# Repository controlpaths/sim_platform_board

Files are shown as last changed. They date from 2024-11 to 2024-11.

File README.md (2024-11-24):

# Platform Board

This board is intended to run real time simulation models and connect them to different commercial platforms like Arduino or TI Launchpad. The core of the board is an FPGA able to run models with time steps up to 100ns.

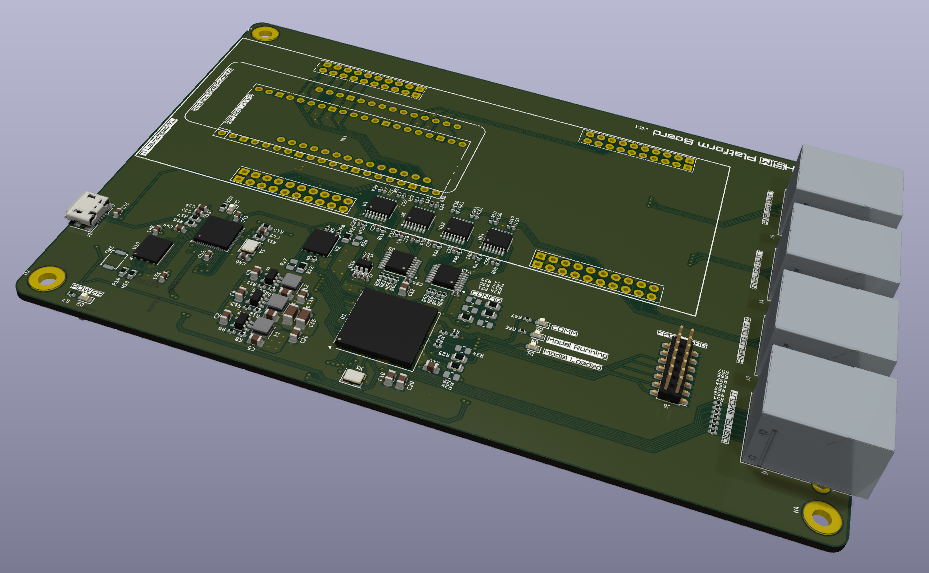
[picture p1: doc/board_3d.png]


The board is based on a 4-layer PCB with an RP2040 as a platform manager. 

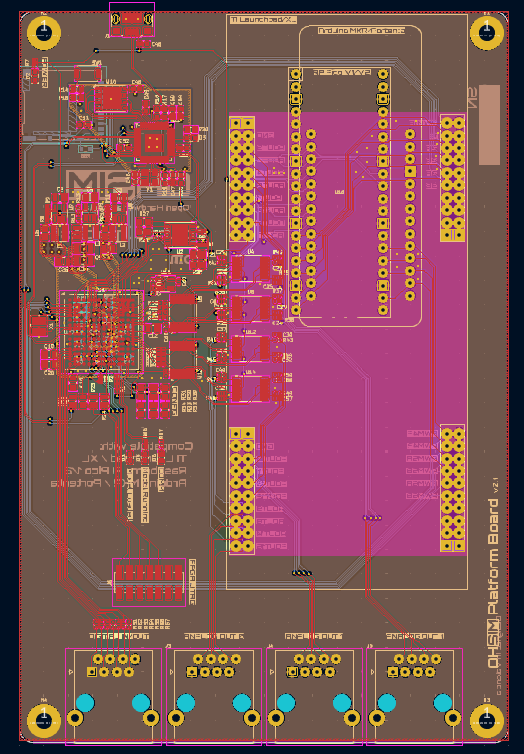
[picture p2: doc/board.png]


## FPGA 

The FPGA used is the AMD Spartan 7 s15 with 15K logic cells. The package used is FTGB196, which makes the board compatible with FPGAs up to 50k logic cells.

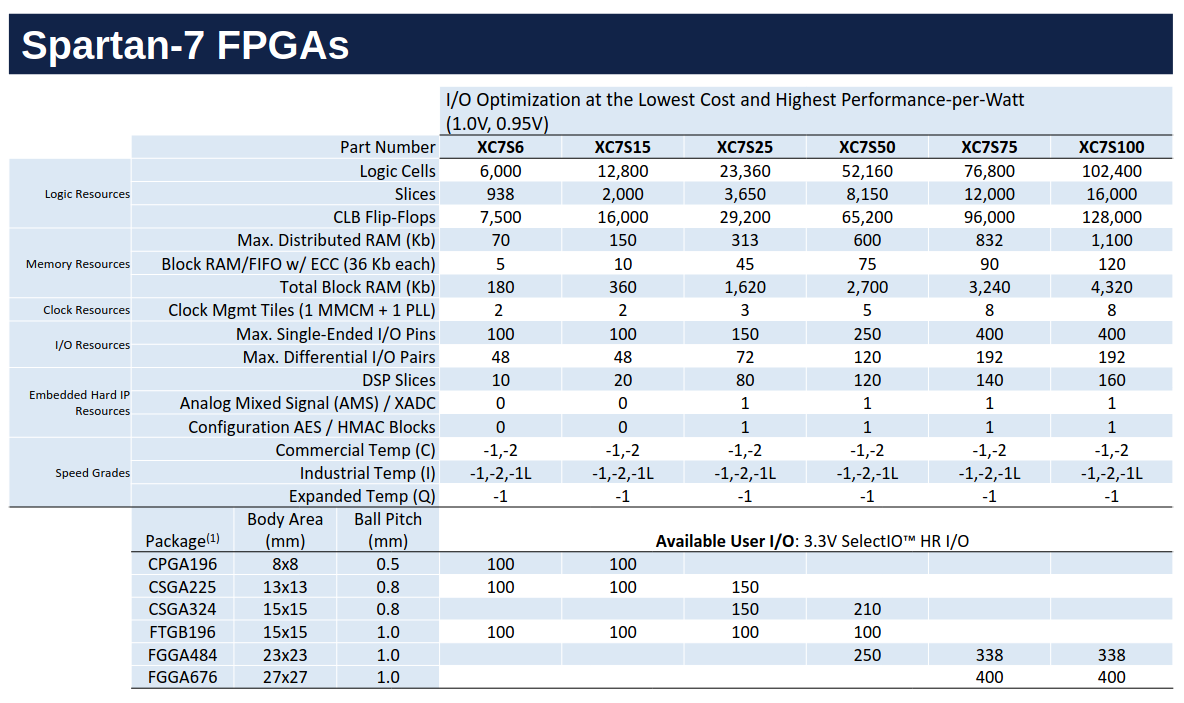
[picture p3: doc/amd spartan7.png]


## DAC outputs

The board features two Digital to Analog converters with 8 channels each. The output range of the DAC is 0 - 3 volts with 12 bit resolutions, and an update rate up to 100 ksps.

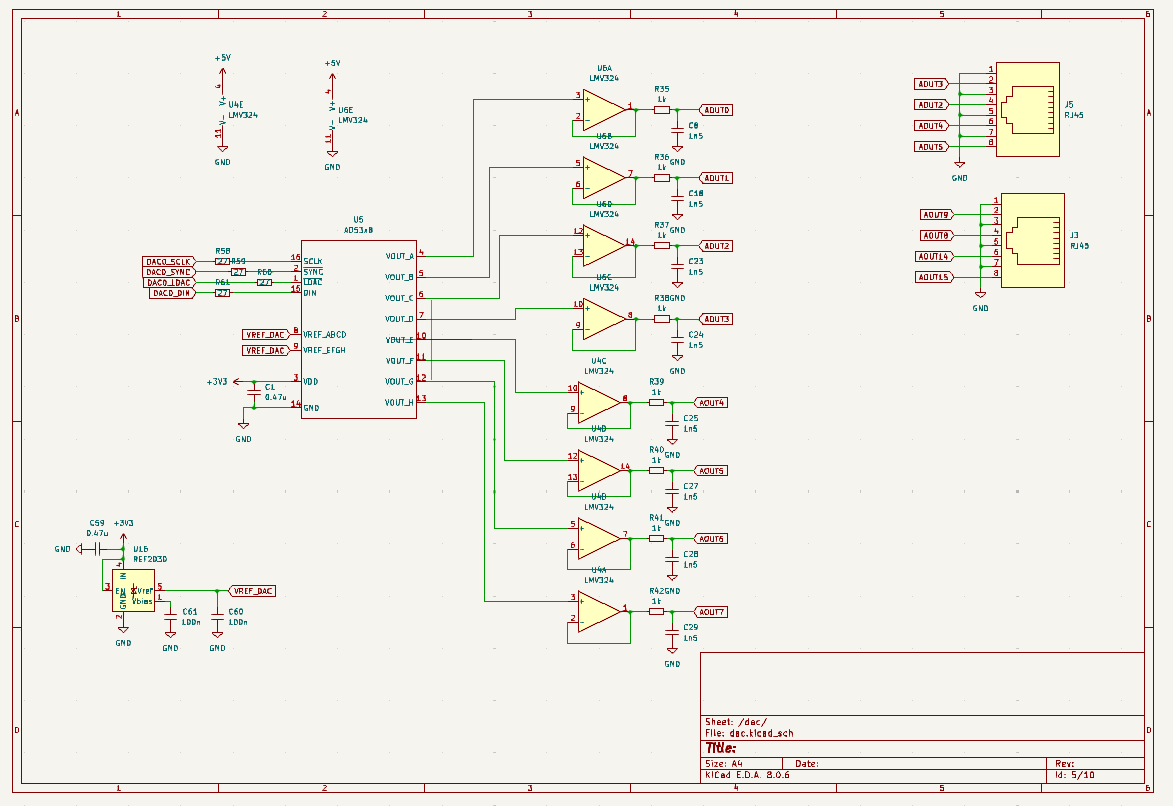
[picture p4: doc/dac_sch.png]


## Control boards

The platform board is compatible with:

- Arduino MKR
- Arduino Portenta
- Raspberry PI Pico
- Texas Instruments Launchpad Boards

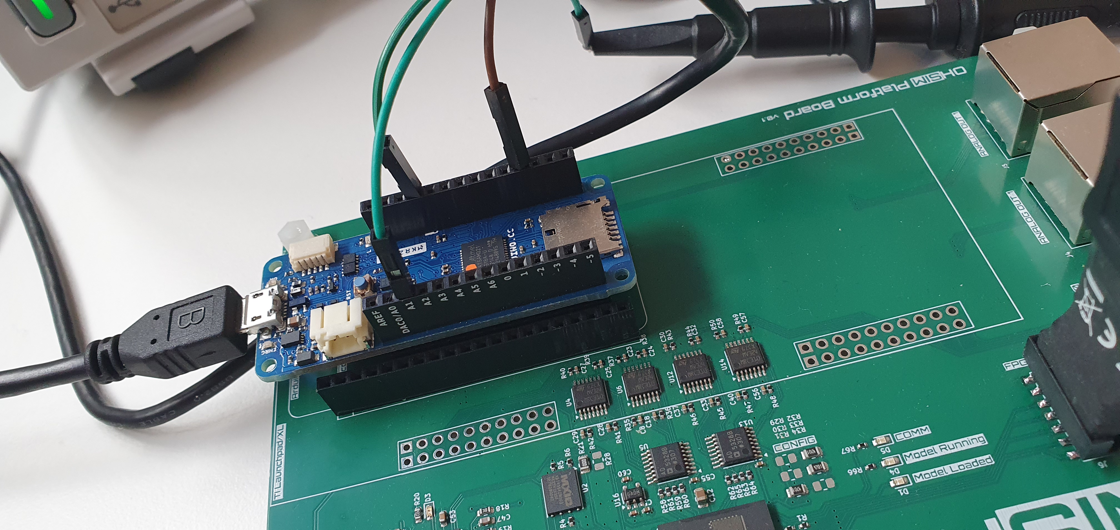
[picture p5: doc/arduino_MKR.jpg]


## Build your own

The Platform Board is open-source, so you can use the output files to manufacture your own in [JLCPCB](https://jlcpcb.com/?from=controlpath). You just need to compress the `production_files` directory, and upload it to [JLCPCB](https://jlcpcb.com/?from=controlpath). 

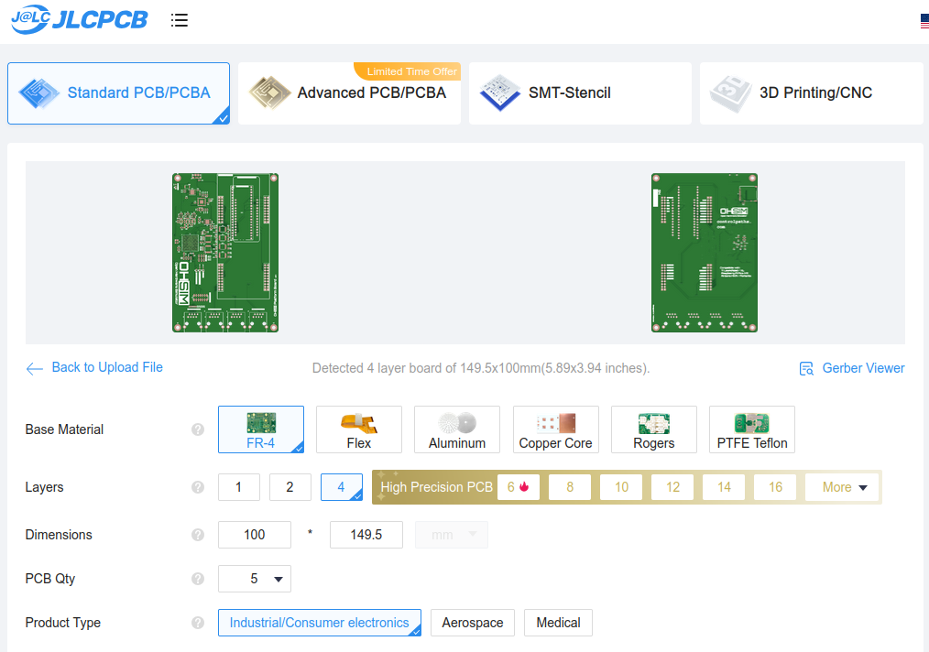
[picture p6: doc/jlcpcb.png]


Remember to change the Surface Finish to **LeadFree HASL** to make your board ROHS compliant.

In a few days, you will receive your board at home.

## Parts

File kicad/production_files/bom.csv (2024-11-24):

Reference | Value | Footprint | Qty | DNP | JLCPCB Part #
C1,C11,C13,C17,C21,C31,C34,C35,C36,C38,C39,C41,C42,C43,C44,C55,C59 | 0.47u | Capacitor_SMD:C_0402_1005Metric | 17 |  | C106255
C2,C3,C4,C10,C12,C14,C16,C19,C20,C22,C26 | 4u7 | Capacitor_SMD:C_0805_2012Metric | 11 |  | C162420
C5,C6,C7 | 10u | Capacitor_SMD:C_0805_2012Metric | 3 |  | C105505
C8,C18,C23,C24,C25,C27,C28,C29,C30,C32,C33,C37,C40,C56,C57,C58 | 1n5 | Capacitor_SMD:C_0402_1005Metric | 16 |  | C106255
C9,C15 | 100u | Capacitor_SMD:C_1206_3216Metric | 2 |  | C268006
C45,C49,C51 | 1u | Capacitor_SMD:C_0603_1608Metric | 3
C46,C47 | 15p | Capacitor_SMD:C_0603_1608Metric | 2
C48,C50,C52,C53,C54 | 100n | Capacitor_SMD:C_0603_1608Metric | 5
C60,C61 | 100n | Capacitor_SMD:C_0402_1005Metric | 2 |  | C106255
D1,D4,D5 | DONE | LED_SMD:LED_0603_1608Metric | 3 |  | C89814
D2 | VCC | LED_SMD:LED_0603_1608Metric | 1 |  | C601673
D3 | LED | LED_SMD:LED_0603_1608Metric | 1 |  | C601673
J1 | USB_B_Micro | Connector_USB:USB_Micro-B_Amphenol_10118193-0001LF_Horizontal | 1 |  | C132562
J2,J3,J4,J5 | RJ45 | Connector_RJ:RJ45_Ninigi_GE | 4 |  | C386758
J7 | Micro_SD_Card_Det_Hirose_DM3AT | Connector_Card:microSD_HC_Hirose_DM3AT-SF-PEJM5 | 1 |  | C114218
L1,L2,L3 | 2u2 | lib:IND_LQH3NPN2R2MMEL | 3 |  | C341775
R1 | 330 | Resistor_SMD:R_0402_1005Metric | 1 |  | C881192
R2,R51,R52,R53,R54,R55,R56,R57 | 100 | Resistor_SMD:R_0402_1005Metric | 8
R3,R4,R5,R6,R66,R67 | 4k7 | Resistor_SMD:R_0402_1005Metric | 6 |  | C3017492
R7 | 10k | Resistor_SMD:R_0402_1005Metric | 1 |  | C328298
R8 | 100k | Resistor_SMD:R_0402_1005Metric | 1 |  | C131362
R9,R12 | 22k | Resistor_SMD:R_0402_1005Metric | 2 |  | C409681
R10 | 240k | Resistor_SMD:R_0402_1005Metric | 1 |  | C323663
R11 | 120k | Resistor_SMD:R_0402_1005Metric | 1 |  | C323683
R13 | 33k | Resistor_SMD:R_0402_1005Metric | 1 |  | C416388
R14,R19 | 1k | Resistor_SMD:R_0603_1608Metric | 2
R15,R18 | 10k | Resistor_SMD:R_0603_1608Metric | 2
R16,R17 | 27 | Resistor_SMD:R_0603_1608Metric | 2
R20,R68 | 4k7 | Resistor_SMD:R_0603_1608Metric | 2
R21,R22 | 0 | Resistor_SMD:R_0805_2012Metric | 2 |  | C3017492
R23,R26,R31,R32,R33 | 4k7 | Resistor_SMD:R_0805_2012Metric | 5
R35,R36,R37,R38,R39,R40,R41,R42,R43,R44,R45,R46,R47,R48,R49,R50 | 1k | Resistor_SMD:R_0402_1005Metric | 16 |  | C409681
R58,R59,R60,R61,R62,R63,R64,R65 | 27 | Resistor_SMD:R_0402_1005Metric | 8
SW1 | SW_Push | Button_Switch_SMD:SW_Push_SPST_NO_Alps_SKRK | 1 |  | C115357
U1 | xc7s25ftgb196 | Package_BGA:Xilinx_FTGB196 | 1 |  | C1521659
U2 | MX25L12833F | Package_SON:WSON-8-1EP_6x5mm_P1.27mm_EP3.4x4mm | 1 |  | C2802978
U4,U6,U12,U14 | LMV324 | Package_SO:TSSOP-14_4.4x5mm_P0.65mm | 4
U5,U13 | AD53x8 | Package_SO:TSSOP-16_4.4x5mm_P0.65mm | 2 |  | C578186
U7,U8,U9 | TLV62565DBVR | Package_TO_SOT_SMD:SOT-23-5 | 3
U10 | W25Q32JVZP | Package_SON:WSON-8-1EP_6x5mm_P1.27mm_EP3.4x4.3mm | 1 |  | C2940197
U11 | RP2040 | Package_DFN_QFN:QFN-56-1EP_7x7mm_P0.4mm_EP3.2x3.2mm | 1
U16 | REF2030 | Package_TO_SOT_SMD:SOT-23-5 | 1 |  | C528704
X1 | SG-8018CE | Crystal:Crystal_SMD_3225-4Pin_3.2x2.5mm | 1 |  | C390488
Y1 | 12MHz | Crystal:Crystal_SMD_3225-4Pin_3.2x2.5mm | 1 |  | C524716

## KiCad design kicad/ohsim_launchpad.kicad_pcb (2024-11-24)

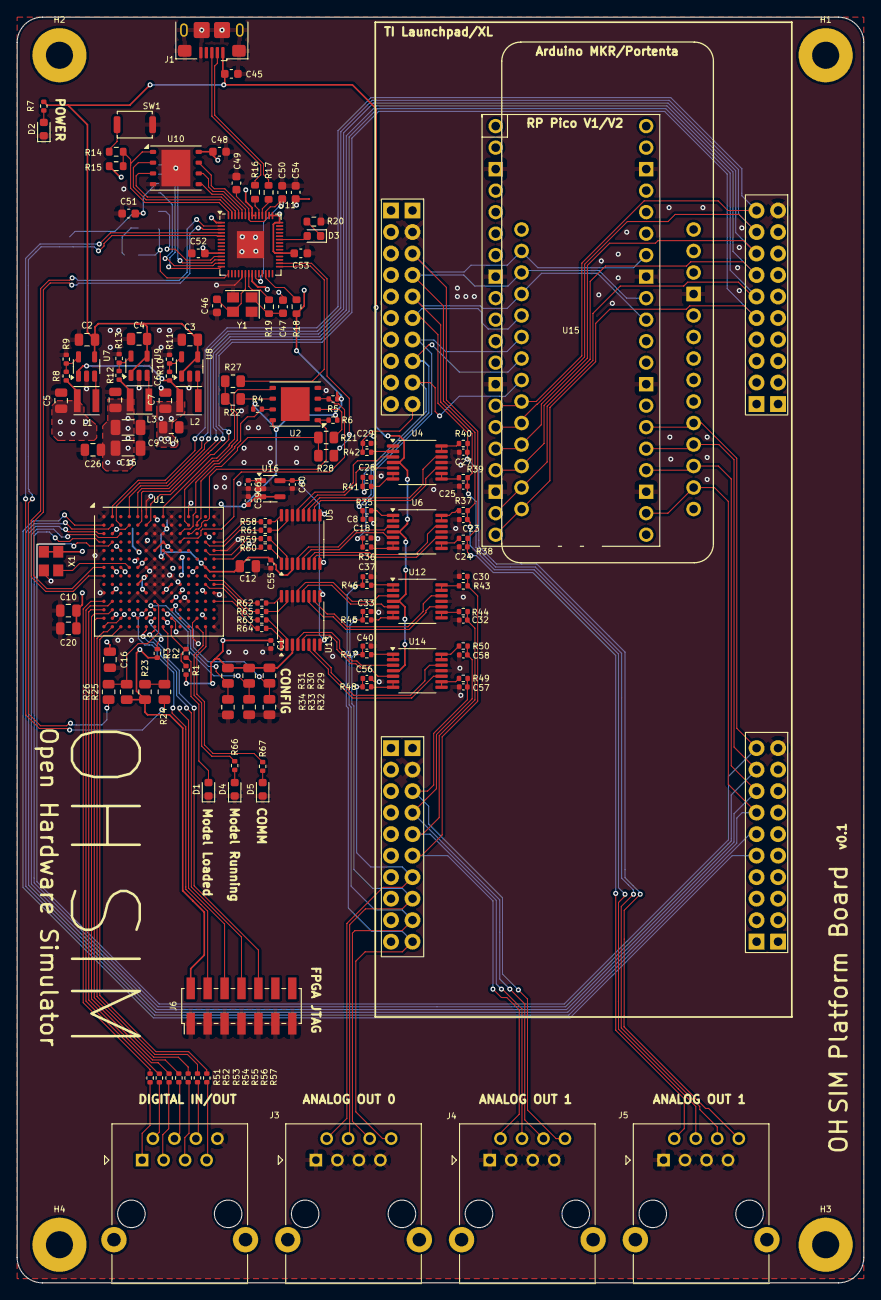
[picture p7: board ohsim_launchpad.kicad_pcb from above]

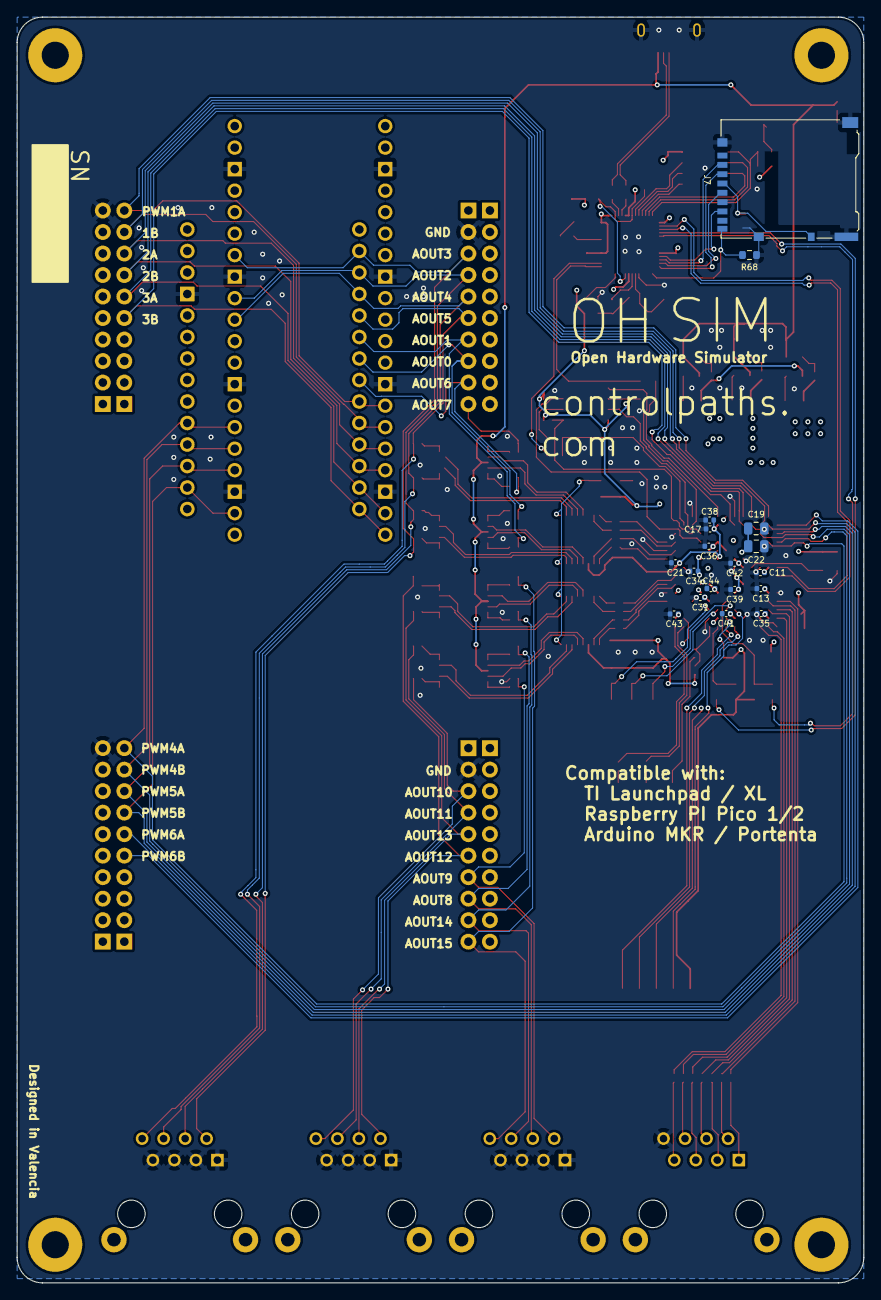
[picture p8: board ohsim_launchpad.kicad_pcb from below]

Board: 4 copper layers, 100.0 x 149.5 mm, 168 parts (18 on the bottom side), 158 nets.

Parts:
A1: Arduino_MKR_WiFi_1010_Socket
C1, C11, C13, C17, C21, C31, C34, C35, C36, C38, C39, C41, C42, C43, C44, C55, C59: 0.47u; C_0402_1005Metric
C2, C3, C4, C10, C12, C14, C16, C19, C20, C22, C26: 4u7; C_0805_2012Metric
C5, C6, C7: 10u; C_0805_2012Metric
C8, C18, C23, C24, C25, C27, C28, C29, C30, C32, C33, C37, C40, C56, C57, C58: 1n5; C_0402_1005Metric
C9, C15: 100u; C_1206_3216Metric
C45, C49, C51: 1u; C_0603_1608Metric
C46, C47: 15p; C_0603_1608Metric
C48, C50, C52, C53, C54: 100n; C_0603_1608Metric
C60, C61: 100n; C_0402_1005Metric
D1, D4, D5: DONE; LED_0603_1608Metric
D2: VCC; LED_0603_1608Metric
D3: LED; LED_0603_1608Metric
H1, H2, H3, H4: MountingHole_Pad; MountingHole_3.2mm_M3_Pad
J1: USB_B_Micro; USB_Micro-B_Amphenol_10118193-0001LF_Horizontal
J2, J3, J4, J5: RJ45; RJ45_Ninigi_GE
J6: Conn_02x07_Odd_Even; PinHeader_2x07_P2.00mm_Vertical_SMD
J7: Micro_SD_Card_Det_Hirose_DM3AT; microSD_HC_Hirose_DM3AT-SF-PEJM5
L1, L2, L3: 2u2; IND_LQH3NPN2R2MMEL
R1: 330; R_0402_1005Metric
R2, R51, R52, R53, R54, R55, R56, R57: 100; R_0402_1005Metric
R3, R4, R5, R6, R66, R67: 4k7; R_0402_1005Metric
R7: 10k; R_0402_1005Metric
R8: 100k; R_0402_1005Metric
R9, R12: 22k; R_0402_1005Metric
R10: 240k; R_0402_1005Metric
R11: 120k; R_0402_1005Metric
R13: 33k; R_0402_1005Metric
R14, R19: 1k; R_0603_1608Metric
R15, R18: 10k; R_0603_1608Metric
R16, R17: 27; R_0603_1608Metric
R20, R68: 4k7; R_0603_1608Metric
R21, R22, R24, R25, R27, R28: 0; R_0805_2012Metric
R23, R26, R29, R30, R31, R32, R33, R34: 4k7; R_0805_2012Metric
R35, R36, R37, R38, R39, R40, R41, R42, R43, R44, R45, R46, R47, R48, R49, R50: 1k; R_0402_1005Metric
R58, R59, R60, R61, R62, R63, R64, R65: 27; R_0402_1005Metric
SW1: SW_Push; SW_Push_SPST_NO_Alps_SKRK
U1: xc7s25ftgb196; Xilinx_FTGB196
U2: MX25L12833F; WSON-8-1EP_6x5mm_P1.27mm_EP3.4x4mm
U3: LAUNCHXL-F28379D; MOD_LAUNCHXL-F28379D
U4, U6, U12, U14: LMV324; TSSOP-14_4.4x5mm_P0.65mm
U5, U13: AD53x8; TSSOP-16_4.4x5mm_P0.65mm
U7, U8, U9: TLV62565DBVR; SOT-23-5
U10: W25Q32JVZP; WSON-8-1EP_6x5mm_P1.27mm_EP3.4x4.3mm
U11: RP2040; QFN-56-1EP_7x7mm_P0.4mm_EP3.2x3.2mm
U15: Pico; RPi_Pico_SMD_TH
U16: REF2030; SOT-23-5
X1: SG-8018CE; Crystal_SMD_3225-4Pin_3.2x2.5mm
Y1: 12MHz; Crystal_SMD_3225-4Pin_3.2x2.5mm

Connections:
+1V0: C7.1, C9.1, C15.1, C19.1, C22.1, C26.1, C36.1, C39.1, C42.1, C44.1, L3.2, R12.1, U1.D6 (VCCINT[10]), U1.D8 (VCCINT[10]), U1.E5 (VCCBRAM[3]), U1.E7 (VCCINT[10]), U1.E9 (VCCINT[10]), U1.F6 (VCCINT[10]), U1.G5 (VCCBRAM[3]), U1.G9 (VCCINT[10]), U1.H6 (VCCINT[10]), U1.J5 (VCCBRAM[3]), U1.J9 (VCCINT[10]), U1.K6 (VCCINT[10]), U1.K8 (VCCINT[10])
+1V1: C49.2, C50.2, U11.23 (DVDD), U11.45 (VREG_VOUT), U11.50 (DVDD)
+1V8: C6.1, C14.1, C31.1, C34.1, L2.2, R10.1, U1.F10 (VCCAUX[4]), U1.H10 (VCCAUX[4]), U1.K10 (VCCAUX[4]), U1.L9 (VCCAUX[4]), U7.1 (EN)
+3V3: C1.1, C5.1, C10.1, C11.1, C12.1, C13.1, C16.1, C17.1, C20.1, C21.1, C35.1, C38.1, C41.1, C43.1, C48.1, C51.2, C52.2, C53.2, C54.2, C55.1, C59.2, J6.2, J7.4 (VDD), J7.10 (DET_A), L1.2, R1.2, R3.2, R4.1, R5.1, R6.1, R8.1, R15.2, R18.2, R23.2, R26.2, R29.1, R30.1, R31.1, U1.B8 (VCCBATT_0), U1.F8 (VCCADC_0), U1.G2 (VCCO_34[3]), U1.G13 (VCCO_14[3]), U1.K2 (VCCO_34[3]), U1.K13 (VCCO_14[3]), U1.N2 (VCCO_34[3]), U1.N6 (VCCO_0[2]), U1.N8 (VCCO_0[2]), U1.N13 (VCCO_14[3]), U2.8 (VCC), U5.3 (VDD), U10.8 (VCC), U11.1 (IOVDD), U11.10 (IOVDD), U11.22 (IOVDD), U11.33 (IOVDD), U11.42 (IOVDD), U11.43 (ADC_AVDD), U11.44 (VREG_IN), U11.48 (USB_VDD), U11.49 (IOVDD), U13.3 (VDD), U16.3 (EN), U16.4 (IN), X1.1 (OE), X1.4 (Vcc)
+5V: C2.1, C3.1, C4.1, C45.2, J1.1 (VBUS), R7.1, U4.4 (V+), U6.4 (V+), U7.4 (VIN), U8.1 (EN), U8.4 (VIN), U9.1 (EN), U9.4 (VIN), U12.4 (V+), U14.4 (V+)
AOUT0: A1.A5, C8.1, R35.2, U3.J3_8 (ADCINB2/ANALOGIN)
AOUT1: A1.A4, C18.1, R36.2, U3.J3_7 (ADCINC2/ANALOGIN)
AOUT2: A1.A1, C23.1, J5.4, R37.2, U3.J3_4 (ADCINC3/ANALOGIN), U15.32 (GPIO27_ADC1)
AOUT3: A1.A0 (A0/DAC), C24.1, J5.2, R38.2, U3.J3_3 (ADCIN14/ANALOGIN), U15.34 (GPIO28_ADC2)
AOUT4: A1.A2, C25.1, J5.6, R39.2, U3.J3_5 (ADCINB3/ANALOGIN), U15.31 (GPIO26_ADC0)
AOUT5: A1.A3, C27.1, J5.8, R40.2, U3.J3_6 (ADCINA3/ANALOGIN)
AOUT6: A1.A6, C28.1, R41.2, U3.J3_9 (ADCINA2/ANALOGIN)
AOUT7: C29.1, R42.2, U3.J3_10 (ADCINA0/ANALOGIN(DACA))
AOUT8: C40.1, J3.4, R47.2, U3.J7_8 (ADCINB4/ANALOGIN)
AOUT9: C56.1, J3.2, R48.2, U3.J7_7 (ADCINC4/ANALOGIN)
AOUT10: C57.1, J4.8, R49.2, U3.J7_3 (ADCIN15/ANALOGIN)
AOUT11: C58.1, J4.6, R50.2, U3.J7_4 (ADCINC5/ANALOGIN)
AOUT12: C30.1, J4.2, R43.2, U3.J7_6 (ADCINA5/ANALOGIN)
AOUT13: C32.1, J4.4, R44.2, U3.J7_5 (ADCINB5/ANALOGIN)
AOUT14: C33.1, J3.6, R45.2, U3.J7_9 (ADCINA4/ANALOGIN)
AOUT15: C37.1, J3.8, R46.2, U3.J7_10 (ADCINA1/ANALOGIN(DACB))
COMM_LED: R67.2, U1.P13 (IO_L22N_T3_D20_14)
DAC0_DIN: R61.2, U1.D13 (IO_L8N_T1_D12_14)
DAC0_LDAC: R60.2, U1.F14 (IO_L9N_T1_DQS_D13_14)
DAC0_SCLK: R58.2, U1.D14 (IO_L11P_T1_SRCC_14)
DAC0_SYNC: R59.2, U1.E13 (IO_L10N_T1_D15_14)
DAC1_DIN: R65.2, U1.J14 (IO_L18N_T2_D27_14)
DAC1_LDAC: R64.2, U1.L14 (IO_L15N_T2_DQS_DOUT_CSO_B_14)
DAC1_SCLK: R62.2, U1.H13 (IO_L14P_T2_SRCC_14)
DAC1_SYNC: R63.2, U1.J13 (IO_L18P_T2_D28_14)
DIO_0: R51.1, U1.L1 (IO_L18N_T2_34)
DIO_1: R52.1, U1.L2 (IO_L22N_T3_34)
DIO_2: R53.1, U1.M1 (IO_L18P_T2_34)
DIO_3: R54.1, U1.M2 (IO_L19N_T3_VREF_34)
DIO_4: R55.1, U1.N1 (IO_L20N_T3_34)
DIO_5: R56.1, U1.P2 (IO_L20P_T3_34)
DIO_6: R57.1, U1.P3 (IO_L21N_T3_DQS_34)
DONE_RP2040: R1.1, R2.2, U1.P9 (DONE_0)
FLASH_CS: R14.1, R15.1, U10.1 (~CS), U11.56 (QSPI_SS)
FLASH_DIN_RP2040: R28.2, U11.30 (GPIO19)
FLASH_RP2040_SCLK: U10.6 (CLK), U11.52 (QSPI_SCLK)
FLASH_SCLK: R22.2, U2.6 (SCLK)
FLASH_SCLK_RP2040: R27.2, U11.29 (GPIO18)
FLASH_SD0: U10.5 (DI(IO0)), U11.53 (QSPI_SD0)
FLASH_SD1: U10.2 (DO(IO1)), U11.55 (QSPI_SD1)
FLASH_SD2: U10.3 (IO2), U11.54 (QSPI_SD2)
FLASH_SD3: U10.7 (IO3), U11.51 (QSPI_SD3)
FPGA_FLASH_SCLK: R22.1, R27.1, U1.A8 (CCLK_0)
FPGA_M0: R31.2, R34.1, U1.M7 (M0_0)
FPGA_M1: R30.2, R33.1, U1.M8 (M1_0)
FPGA_M2: R29.2, R32.1, U1.M9 (M2_0)
GND: A1.GND, C1.2, C2.2, C3.2, C4.2, C5.2, C6.2, C7.2, C8.2, C9.2, C10.2, C11.2, C12.2, C13.2, C14.2, C15.2, C16.2, C17.2, C18.2, C19.2, C20.2, C21.2, C22.2, C23.2, C24.2, C25.2, C26.2, C27.2, C28.2, C29.2, C30.2, C31.2, C32.2, C33.2, C34.2, C35.2, C36.2, C37.2, C38.2, C39.2, C40.2, C41.2, C42.2, C43.2, C44.2, C45.1, C46.1, C47.1, C48.2, C49.1, C50.1, C51.1, C52.1, C53.1, C54.1, C55.2, C56.2, C57.2, C58.2, C59.1, C60.2, C61.2, D1.1 (K), D2.1 (K), D4.1 (K), D5.1 (K), J1.5 (GND), J1.6 (Shield), J2.8, J3.1, J3.3, J3.5, J3.7, J4.1, J4.3, J4.5, J4.7, J5.1, J5.3, J5.5, J5.7, J6.1, J6.3, J6.5, J6.7, J6.9, J6.11, J6.13, J7.6 (VSS), J7.11 (SHIELD), R9.2, R11.2, R13.2, R20.1, R32.2, R33.2, R34.2, R68.1, SW1.1, U1.A1 (GND[50]), U1.A6 (GND[50]), U1.A9 (GND[50]), U1.A11 (GND[50]), U1.A14 (GND[50]), U1.B4 (GND[50]), U1.B7 (GND[50]), U1.B9 (GND[50]), U1.C2 (GND[50]), U1.C6 (GND[50]), U1.C7 (GND[50]), U1.C8 (GND[50]), U1.C9 (GND[50]), U1.C13 (GND[50]), U1.D5 (GND[50]), U1.D7 (GND[50]), U1.D9 (GND[50]), U1.D11 (GND[50]), U1.E1 (GND[50]), U1.E3 (GND[50]), U1.E6 (GND[50]), U1.E8 (GND[50]), U1.E10 (GND[50]), U1.E14 (GND[50]), U1.F5 (GND[50]), U1.F7 (GNDADC_0), U1.F9 (GND[50]), U1.G3 (GND[50]), U1.G6 (GND[50]), U1.G7 (VREFN_0), U1.G8 (VP_0), U1.G10 (GND[50]), U1.G12 (GND[50]), U1.H5 (GND[50]), U1.H7 (VN_0), U1.H8 (VREFP_0), U1.H9 (GND[50]), U1.J6 (GND[50]), U1.J7 (DXN_0), U1.J8 (DXP_0), U1.J10 (GND[50]), U1.K1 (GND[50]), U1.K5 (GND[50]), U1.K7 (GND[50]), U1.K9 (GND[50]), U1.K14 (GND[50]), U1.L4 (GND[50]), U1.L6 (GND[50]), U1.L8 (GND[50]), U1.L10 (GND[50]), U1.L11 (GND[50]), U1.N3 (GND[50]), U1.N5 (GND[50]), U1.N9 (GND[50]), U1.N12 (GND[50]), U1.P1 (GND[50]), U1.P14 (GND[50]), U2.4 (GND), U3.J2_10 (GND_J2), U3.J3_2 (GND_J3), U3.J6_10 (GND_J6), U3.J7_2 (GND_J7), U4.11 (V-), U5.14 (GND), U6.11 (V-), U7.2 (GND), U8.2 (GND), U9.2 (GND), U10.4 (GND), U10.9 (EP), U11.19 (TESTEN), U11.57 (GND), U12.11 (V-), U13.14 (GND), U14.11 (V-), U15.3 (GND), U15.8 (GND), U15.13 (GND), U15.18 (GND), U15.23 (GND), U15.28 (GND), U15.33 (AGND), U15.38 (GND), U16.2 (GND), X1.2 (GND), Y1.2, Y1.4
INIT_B: R23.1, R24.1, U1.P8 (INIT_B_0)
INIT_B_RP2040: R24.2, U11.4 (GPIO2)
JTAG_TCK: J6.6, U1.A7 (TCK_0)
JTAG_TDI: J6.10, U1.P7 (TDI_0)
JTAG_TDO: J6.8, U1.P6 (TDO_0)
JTAG_TMS: J6.4, U1.M6 (TMS_0)
MODEL_RUNNING: R66.2, U1.P12 (IO_L22P_T3_D21_14)
unnamed: C47.2, R19.1, Y1.1
unnamed: D1.2 (A), R2.1
unnamed: D2.2 (A), R7.2
unnamed: D3.2 (A), U11.37 (GPIO25)
unnamed: D3.1 (K), R20.2
unnamed: D4.2 (A), R66.1
unnamed: D5.2 (A), R67.1
unnamed: J1.3 (D+), R16.1
unnamed: J1.2 (D-), R17.1
unnamed: J2.1, R51.2
unnamed: J2.2, R52.2
unnamed: J2.3, R53.2
unnamed: J2.4, R54.2
unnamed: J2.5, R55.2
unnamed: J2.6, R56.2
unnamed: J2.7, R57.2
unnamed: R14.2, SW1.2
unnamed: R3.1, U1.N7 (CFGBVS_0)
unnamed: R21.1, R28.1, U1.B12 (IO_L1N_T0_D01_DIN_14)
unnamed: U1.B11 (IO_L1P_T0_D00_MOSI_14), U2.5 (SI/SIO0)
unnamed: R4.2, U1.C10 (IO_L2N_T0_D03_14), U2.7 (~RESET/SIO3)
unnamed: R5.2, U1.D10 (IO_L2P_T0_D02_14), U2.3 (~WP/SIO2)
unnamed: R6.2, U1.C11 (IO_L6P_T0_FCS_B_14), U2.1 (~CS)
unnamed: U1.G4 (IO_L12P_T1_MRCC_34), X1.3 (OUT)
unnamed: R21.2, U2.2 (SO/SIO1)
unnamed: U4.3 (+), U5.13 (VOUT_H)
unnamed: R42.1, U4.1, U4.2 (-)
unnamed: U4.5 (+), U5.12 (VOUT_G)
unnamed: R41.1, U4.6 (-), U4.7
unnamed: U4.10 (+), U5.10 (VOUT_E)
unnamed: R39.1, U4.8, U4.9 (-)
unnamed: U4.12 (+), U5.11 (VOUT_F)
unnamed: R40.1, U4.13 (-), U4.14
unnamed: R61.1, U5.15 (DIN)
unnamed: R58.1, U5.16 (SCLK)
unnamed: U5.4 (VOUT_A), U6.3 (+)
unnamed: U5.5 (VOUT_B), U6.5 (+)
unnamed: U5.6 (VOUT_C), U6.12 (+)
unnamed: U5.7 (VOUT_D), U6.10 (+)
unnamed: R60.1, U5.1 (~LDAC)
unnamed: R59.1, U5.2 (~SYNC)
unnamed: R35.1, U6.1, U6.2 (-)
unnamed: R36.1, U6.6 (-), U6.7
unnamed: R38.1, U6.8, U6.9 (-)
unnamed: R37.1, U6.13 (-), U6.14
unnamed: R8.2, R9.1, U7.5 (FB)
unnamed: L1.1, U7.3 (SW)
unnamed: R10.2, R11.1, U8.5 (FB)
unnamed: L2.1, U8.3 (SW)
unnamed: R12.2, R13.1, U9.5 (FB)
unnamed: L3.1, U9.3 (SW)
unnamed: R18.1, U11.26 (RUN)
unnamed: R17.2, U11.46 (USB_DM)
unnamed: R16.2, U11.47 (USB_DP)
unnamed: C46.2, U11.20 (XIN), Y1.3
unnamed: R19.2, U11.21 (XOUT)
unnamed: U12.3 (+), U13.13 (VOUT_H)
unnamed: R46.1, U12.1, U12.2 (-)
unnamed: U12.5 (+), U13.12 (VOUT_G)
unnamed: R45.1, U12.6 (-), U12.7
unnamed: U12.10 (+), U13.11 (VOUT_F)
unnamed: R44.1, U12.8, U12.9 (-)
unnamed: U12.12 (+), U13.10 (VOUT_E)
unnamed: R43.1, U12.13 (-), U12.14
unnamed: R65.1, U13.15 (DIN)
unnamed: R62.1, U13.16 (SCLK)
unnamed: U13.4 (VOUT_A), U14.3 (+)
unnamed: U13.5 (VOUT_B), U14.5 (+)
unnamed: U13.6 (VOUT_C), U14.10 (+)
unnamed: U13.7 (VOUT_D), U14.12 (+)
unnamed: R64.1, U13.1 (~LDAC)
unnamed: R63.1, U13.2 (~SYNC)
unnamed: R47.1, U14.1, U14.2 (-)
unnamed: R48.1, U14.6 (-), U14.7
unnamed: R49.1, U14.8, U14.9 (-)
unnamed: R50.1, U14.13 (-), U14.14
unnamed: C61.1, U16.1 (Vbias)
PROGRAM_B: R25.1, R26.1, U1.L7 (PROGRAM_B_0)
PROGRAM_B_RP2040: R25.2, U11.5 (GPIO3)
PWM1A: A1.D0, U1.A2 (IO_L3N_T0_DQS_34), U3.J4_10 (GPIO0/PWMOUT1A), U15.14 (GPIO10)
PWM1B: A1.D1, U1.B3 (IO_L3P_T0_DQS_34), U3.J4_9 (GPIO1/PWMOUT1B), U15.15 (GPIO11)
PWM2A: A1.D2, U1.A4 (IO_L2P_T0_34), U3.J4_8 (GPIO2//PWMOUT2A), U15.16 (GPIO12)
PWM2B: A1.D3, U1.A5 (IO_L4N_T0_34), U3.J4_7 (GPIO3/PWMOUT2B), U15.17 (GPIO13)
PWM3A: A1.D4, U1.B5 (IO_L4P_T0_34), U3.J4_6 (GPIO4/PWMOUT3A), U15.19 (GPIO14)
PWM3B: A1.D5, U1.B6 (IO_0_34), U3.J4_5 (GPIO5/PWMOUT3B), U15.20 (GPIO15)
PWM4A: A1.D10 (D10_MISO), U1.D2 (IO_L10N_T1_34), U3.J8_10 (GPIO6/PWMOUT4A), U15.26 (GPIO20)
PWM4B: A1.D9 (D9_SCK), U1.D1 (IO_L11P_T1_SRCC_34), U3.J8_9 (GPIO7/PWMOUT4B), U15.25 (GPIO19)
PWM5A: A1.D8 (D8_MOSI), U1.C3 (IO_L1N_T0_34), U3.J8_8 (GPIO8/PWMOUT5A), U15.24 (GPIO18)
PWM5B: A1.D7, U1.C1 (IO_L11N_T1_SRCC_34), U3.J8_7 (GPIO9/PWMOUT5B), U15.22 (GPIO17)
PWM6A: U1.B2 (IO_L5P_T0_34), U3.J8_6 (GPIO10/PWMOUT6A)
PWM6B: U1.B1 (IO_L5N_T0_34), U3.J8_5 (GPIO11/PWMOUT6B)
RP2040_UART0_RX: U1.G1 (IO_L9P_T1_DQS_34), U11.3 (GPIO1)
RP2040_UART0_TX: U1.H1 (IO_L14N_T2_SRCC_34), U11.2 (GPIO0)
VREF_DAC: C60.1, U5.8 (VREF_ABCD), U5.9 (VREF_EFGH), U13.8 (VREF_ABCD), U13.9 (VREF_EFGH), U16.5 (Vref)
sdcard_cs: J7.2 (DAT3/CD), U11.12 (GPIO9)
sdcard_detection: J7.9 (DET_B), R68.2, U11.15 (GPIO12)
sdcard_miso: J7.7 (DAT0), U11.11 (GPIO8)
sdcard_mosi: J7.3 (CMD), U11.14 (GPIO11)
sdcard_sclk: J7.5 (CLK), U11.13 (GPIO10)
